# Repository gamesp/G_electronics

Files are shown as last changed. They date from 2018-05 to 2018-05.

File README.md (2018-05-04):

## Pi GAMESP Robot Electronics

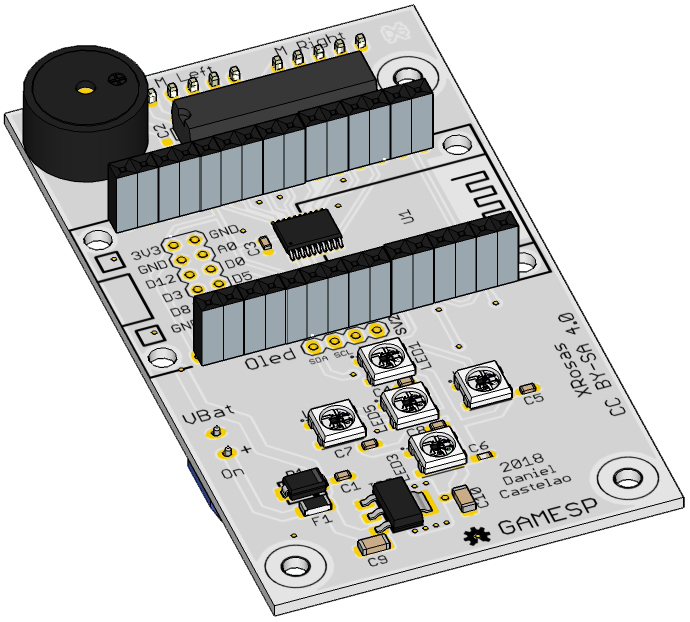
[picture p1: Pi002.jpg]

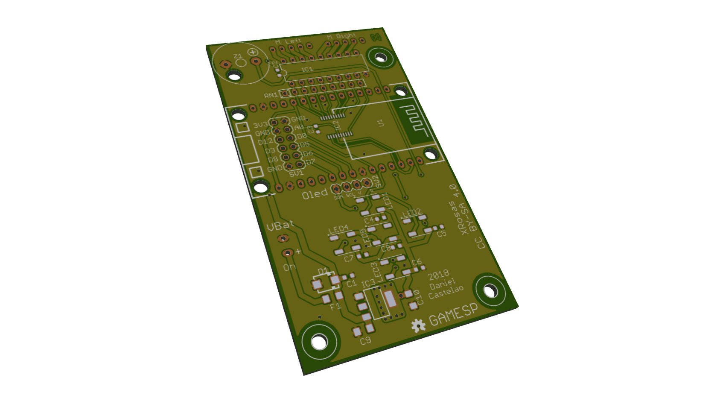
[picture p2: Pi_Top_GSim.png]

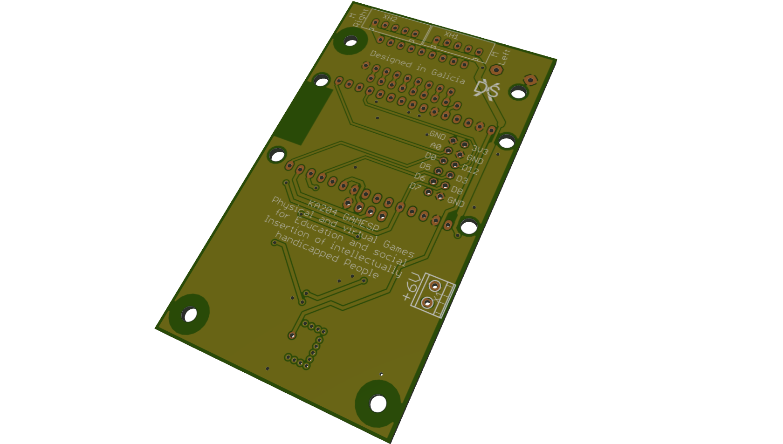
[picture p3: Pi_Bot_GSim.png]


## Catalog

- Esquematic and PCB (by [Xdesig][XDE01])

- Gerber 274 machines compatible.

- STL for slicer

- Images mounting Process and connections

- 3d sim (SketchUp, Private use)

## NodeMCU
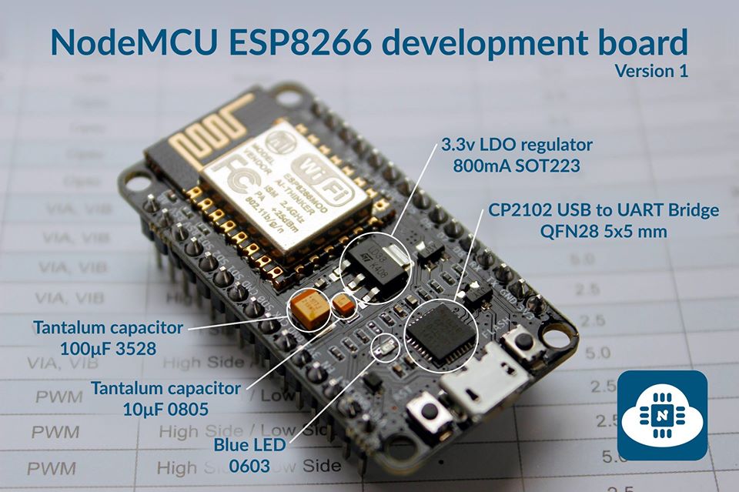
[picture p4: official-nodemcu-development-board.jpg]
devkit-v1.0
  

- devkit-v1.0 [NodeMCU]

- NodeMCU License [NodeMCU_LIC]

## License

Every content in this repo, otherwise specified under subdirectories, is
licensed under [Creative Commons BY-SA](LICENSE).

[XDE01]: https://twitter.com/xdesig

[NodeMCU_LIC]: https://github.com/nodemcu/nodemcu-devkit-v1.0/blob/master/LICENSE
[NodeMCU]: https://github.com/nodemcu/nodemcu-devkit-v1.0

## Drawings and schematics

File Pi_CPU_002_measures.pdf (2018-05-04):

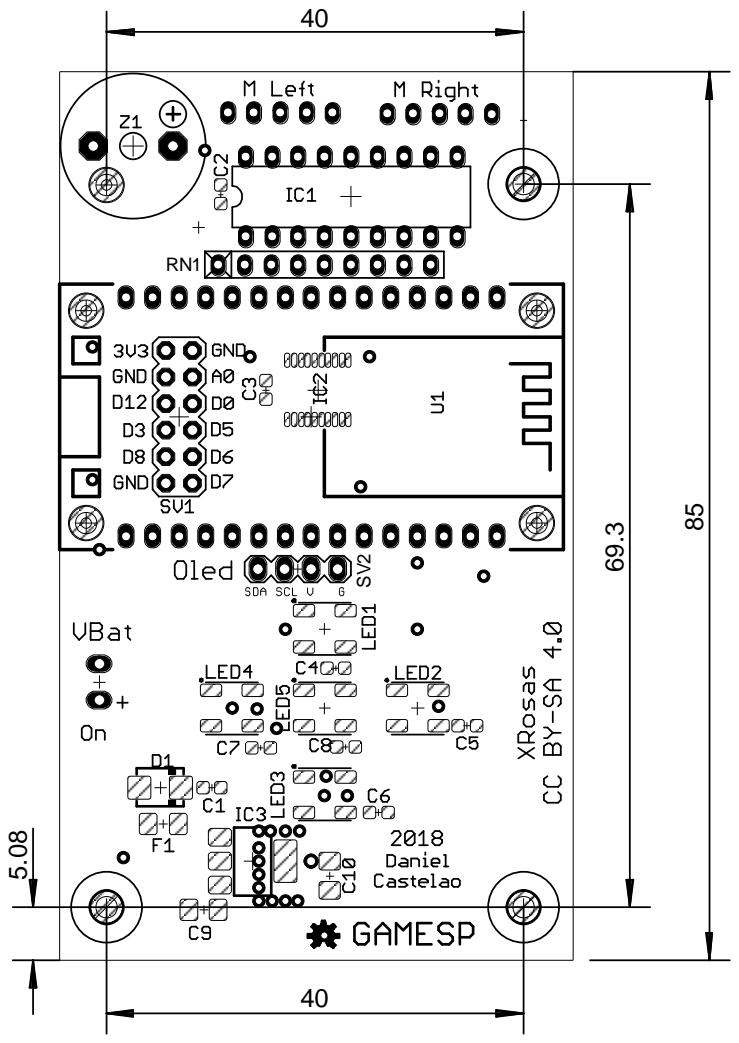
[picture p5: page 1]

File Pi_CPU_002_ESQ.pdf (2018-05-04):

## NodeMCU DEVKIT V1.0

## Steepers

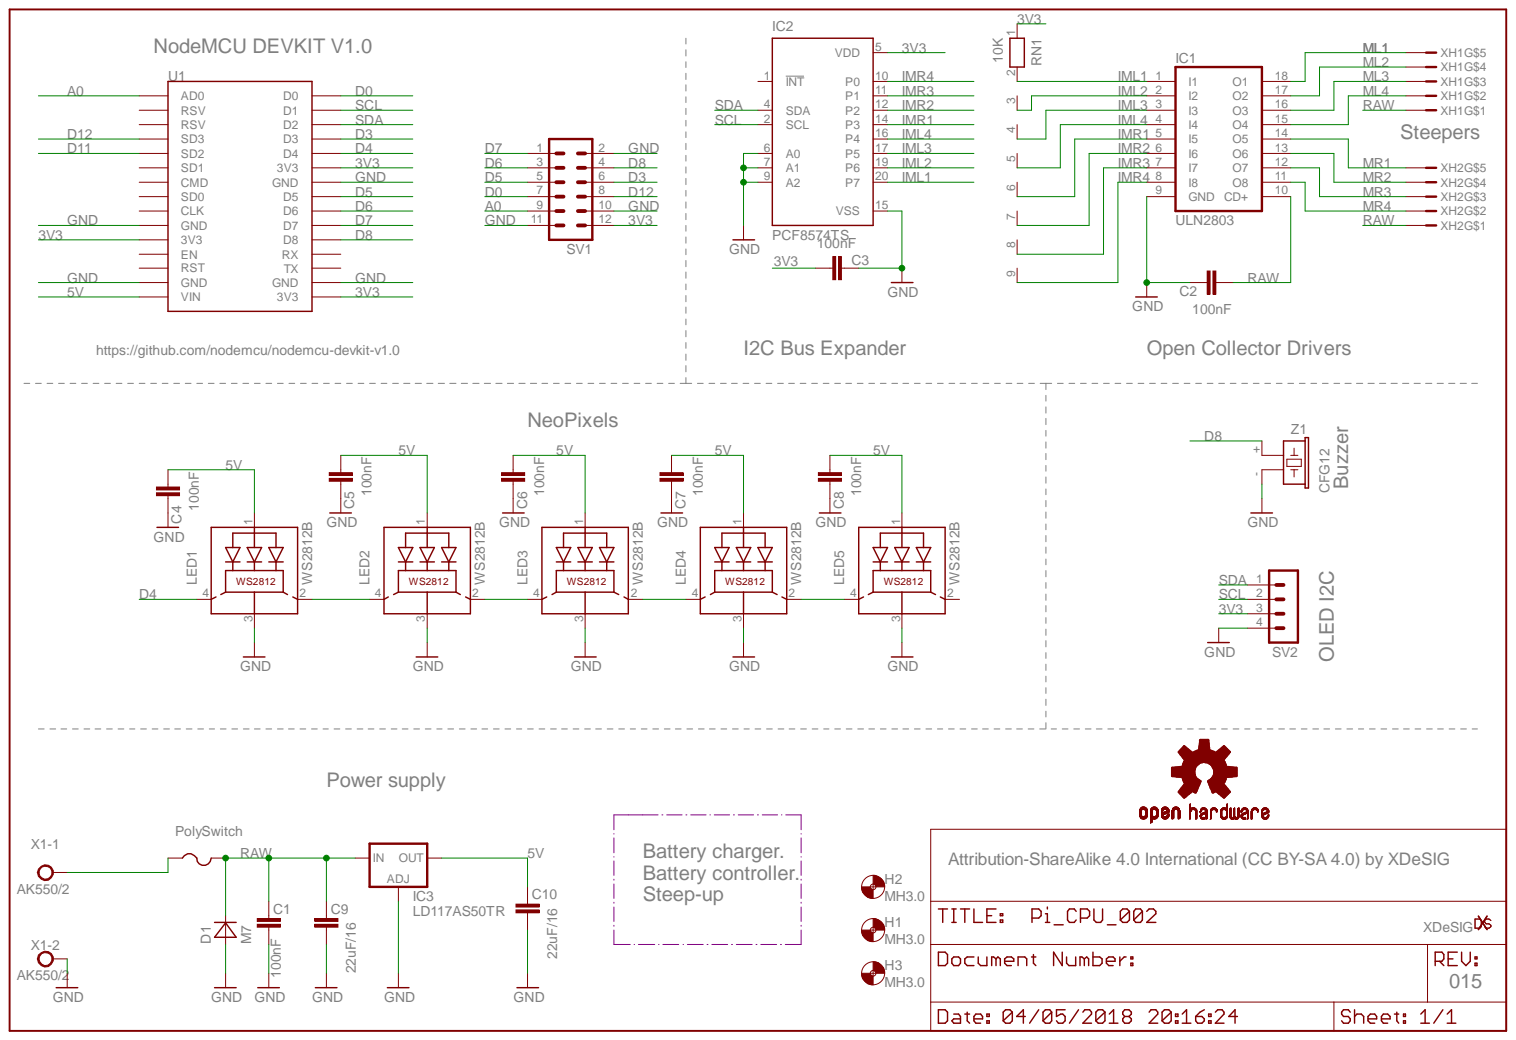
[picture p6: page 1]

https://github.com/nodemcu/nodemcu-devkit-v1.0

Attribution-ShareAlike 4.0 International (CC BY-SA 4.0) by XDeSIG

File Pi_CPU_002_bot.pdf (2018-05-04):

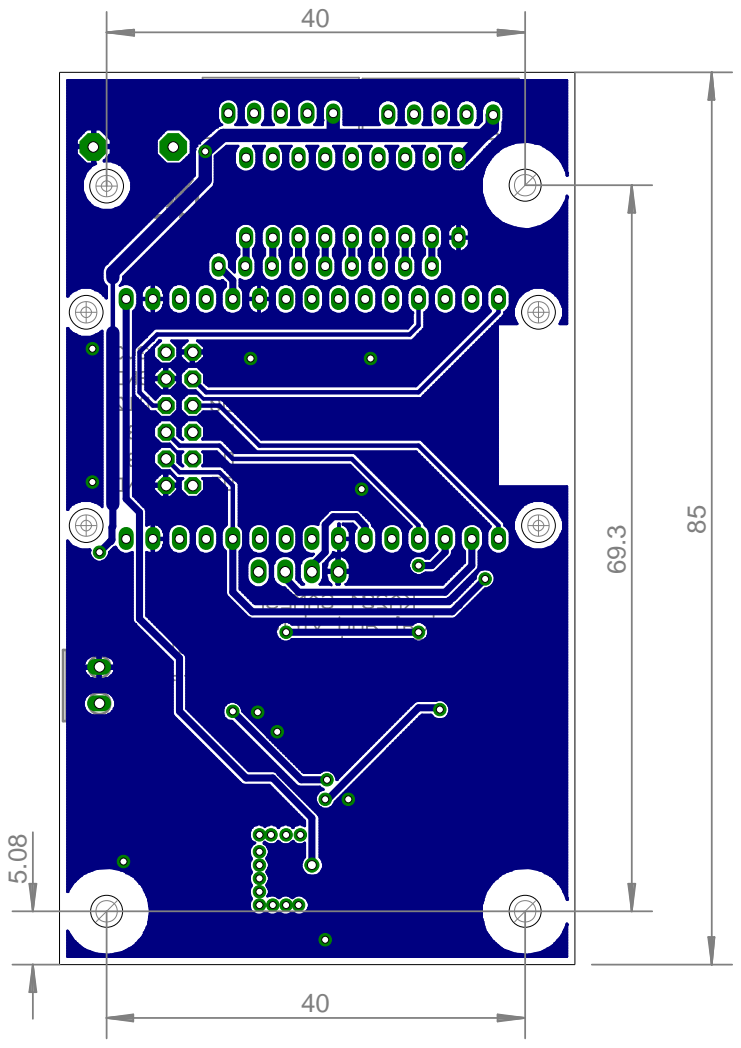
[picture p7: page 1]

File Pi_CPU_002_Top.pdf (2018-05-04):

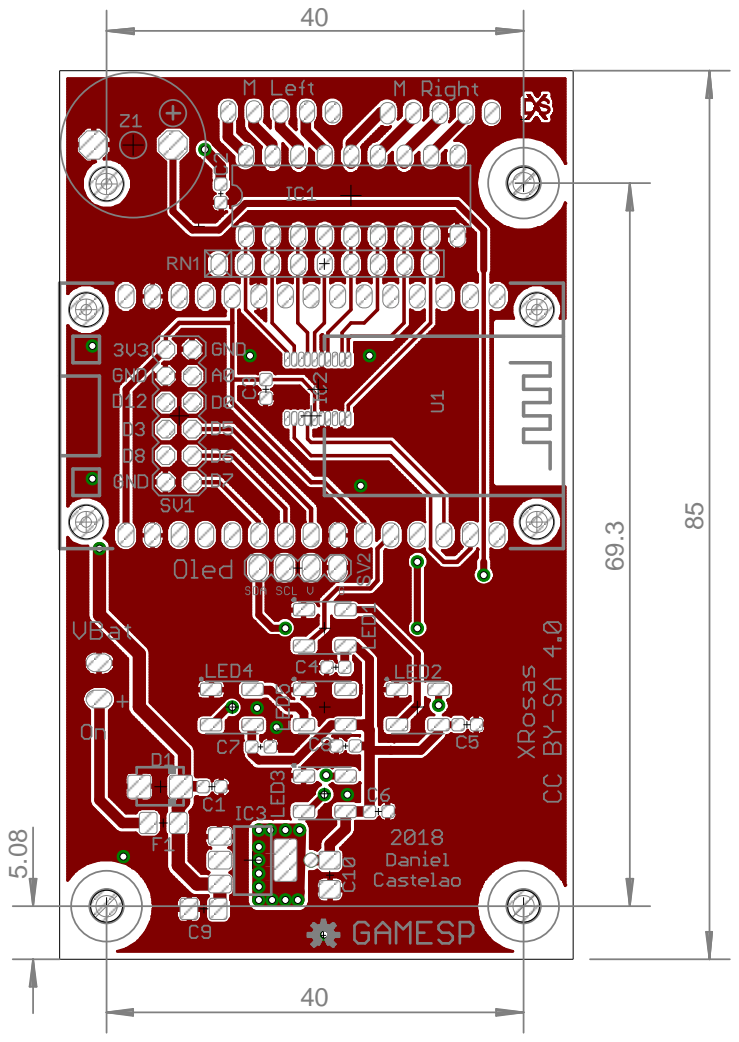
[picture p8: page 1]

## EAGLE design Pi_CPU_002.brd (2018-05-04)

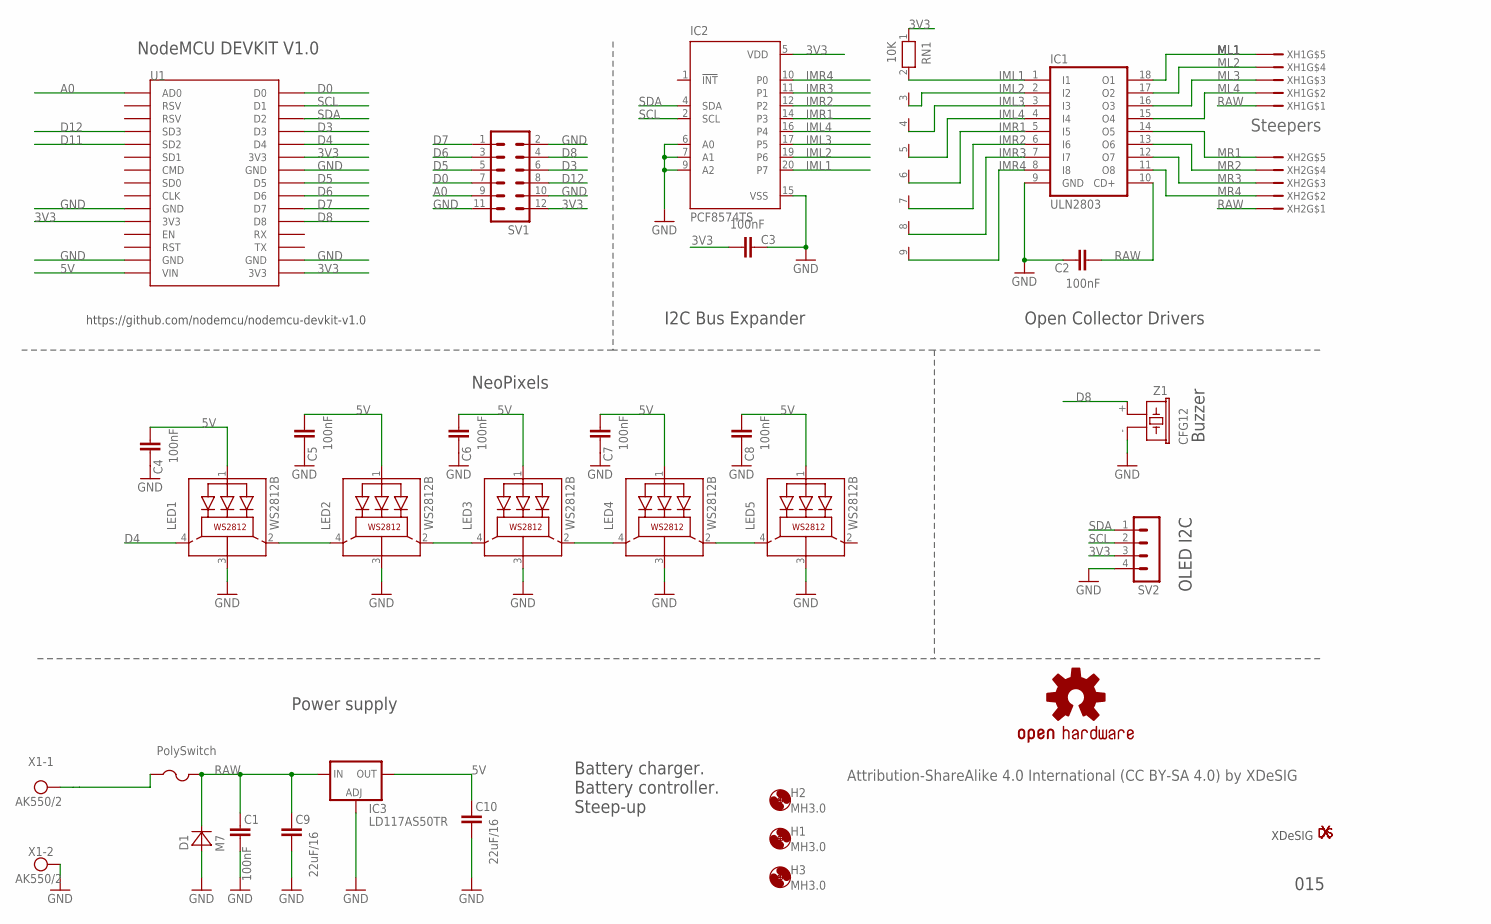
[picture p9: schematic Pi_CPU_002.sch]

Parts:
C1, C2, C3, C4, C5, C6, C7, C8: 100nF; C0603K
C9, C10: 22uF/16; C1206
D1: M7; SMA
F1: PolySwitch; R1206
H1, H2, H3: MH3.0; 3,0
IC1: ULN2803; DIL18
IC2: PCF8574TS; SSOP20
IC3: LD117AS50TR; SOT223
LED1, LED2, LED3, LED4, LED5: WS2812B; 5050-4
LOGO2: OSHW-LOGOS; OSHW-LOGO-S
RN1: 10K; RN-9
SV1: MA06-2
SV2: MA04-1
U1: ESP12E_DEVKIT
U$13: XDESIG_XDESIG21; XDESIG_XDESIG
X1: AK550/2
XDS1: XDESIG; XDESIG_CU_2
XH1, XH2: B5B-XH-A
Z1: CFG12; F/CM12P

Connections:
3V3: C3.2, IC2.5 (VDD), RN1.1, SV1.12, SV2.3, U1.3V3@0 (3V3), U1.3V3@1 (3V3), U1.3V3@2 (3V3)
5V: C4.2, C5.2, C6.2, C7.2, C8.2, C10.2, IC3.4 (OUT), LED1.1 (LEDVDD), LED2.1 (LEDVDD), LED3.1 (LEDVDD), LED4.1 (LEDVDD), LED5.1 (LEDVDD), U1.VIN
A0: SV1.9, U1.AD0
D0: SV1.7, U1.D0
D3: SV1.6, U1.D3
D4: LED1.4 (DI), U1.D4
D5: SV1.5, U1.D5
D6: SV1.3, U1.D6
D7: SV1.1, U1.D7
D8: SV1.4, U1.D8, Z1.+ (1)
D11: U1.SD2
D12: SV1.8, U1.SD3
GND: C1.1, C2.1, C3.1, C4.1, C5.1, C6.1, C7.1, C8.1, C9.1, C10.1, D1.A, IC1.9 (GND), IC2.6 (A0), IC2.7 (A1), IC2.9 (A2), IC2.15 (VSS), IC3.1 (ADJ), LED1.3 (GND), LED2.3 (GND), LED3.3 (GND), LED4.3 (GND), LED5.3 (GND), SV1.2, SV1.10, SV1.11, SV2.4, U1.GND@0 (GND), U1.GND@1 (GND), U1.GND@2 (GND), U1.GND@3 (GND), X1.2, Z1.- (2)
IML1: IC1.1 (I1), IC2.20 (P7), RN1.2
IML2: IC1.2 (I2), IC2.19 (P6), RN1.3
IML3: IC1.3 (I3), IC2.17 (P5), RN1.4
IML4: IC1.4 (I4), IC2.16 (P4), RN1.5
IMR1: IC1.5 (I5), IC2.14 (P3), RN1.6
IMR2: IC1.6 (I6), IC2.12 (P2), RN1.7
IMR3: IC1.7 (I7), IC2.11 (P1), RN1.8
IMR4: IC1.8 (I8), IC2.10 (P0), RN1.9
ML1: IC1.18 (O1), XH1.P$5
ML2: IC1.17 (O2), XH1.P$4
ML3: IC1.16 (O3), XH1.P$3
ML4: IC1.15 (O4), XH1.P$2
MR1: IC1.14 (O5), XH2.P$5
MR2: IC1.13 (O6), XH2.P$4
MR3: IC1.12 (O7), XH2.P$3
MR4: IC1.11 (O8), XH2.P$2
unnamed: F1.1, X1.1
unnamed: LED1.2 (DO), LED2.4 (DI)
unnamed: LED3.2 (DO), LED4.4 (DI)
unnamed: LED2.2 (DO), LED3.4 (DI)
unnamed: LED4.2 (DO), LED5.4 (DI)
RAW: C1.2, C2.2, C9.2, D1.C, F1.2, IC1.10 (CD+), IC3.3 (IN), XH1.P$1, XH2.P$1
SCL: IC2.2 (SCL), SV2.2, U1.D1
SDA: IC2.4 (SDA), SV2.1, U1.D2

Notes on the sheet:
Steepers
Attribution-ShareAlike 4.0 International (CC BY-SA 4.0) by XDeSIG
XDeSIG
015
OLED I2C
NeoPixels
NodeMCU DEVKIT V1.0
I2C Bus Expander
Open Collector Drivers
Buzzer
Power supply
Battery charger. Battery controller. Steep-up
https://github.com/nodemcu/nodemcu-devkit-v1.0

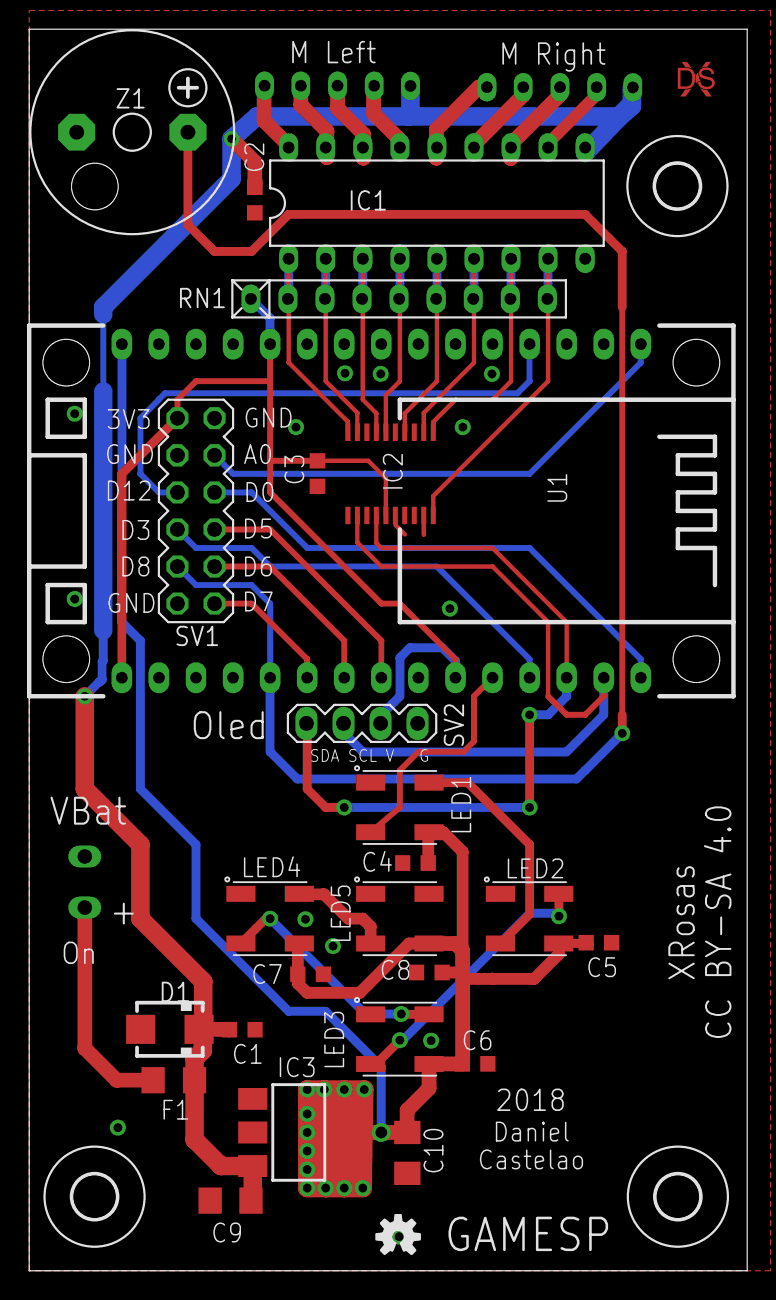
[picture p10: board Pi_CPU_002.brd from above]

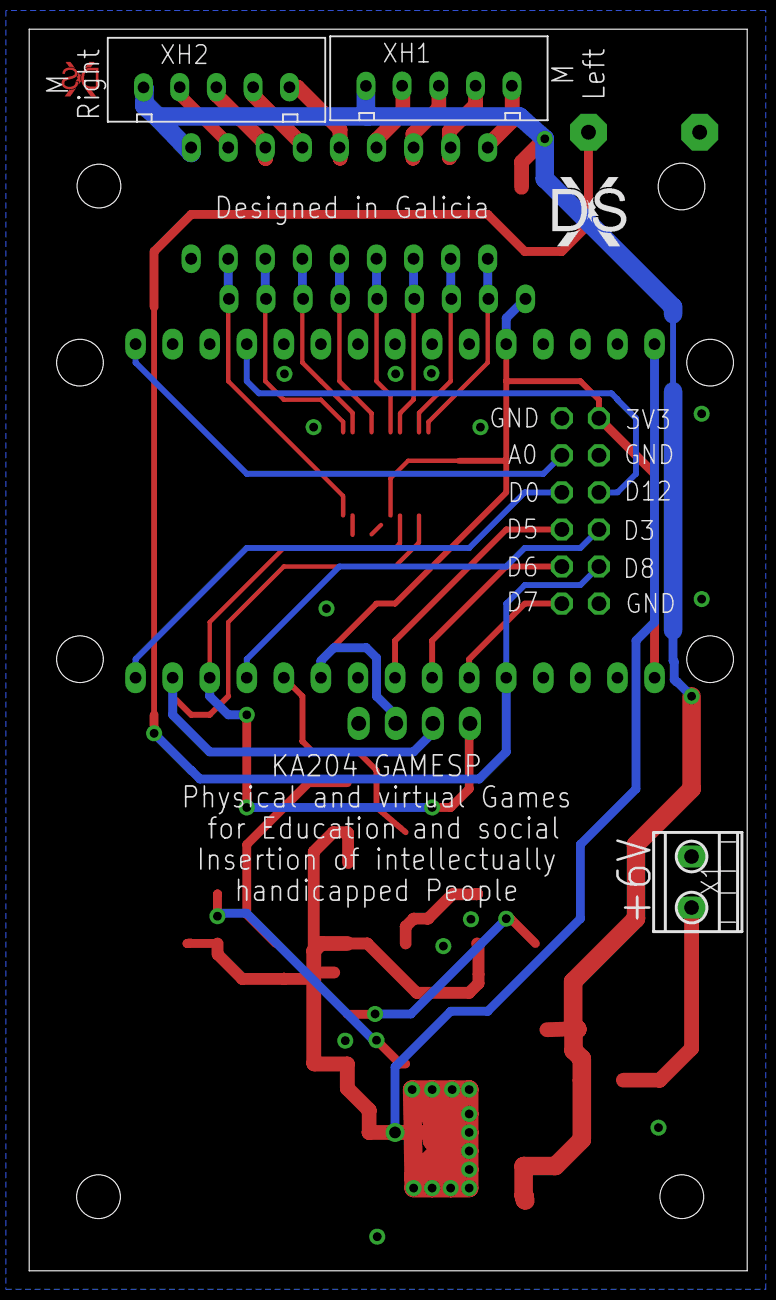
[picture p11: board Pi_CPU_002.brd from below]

Board: 2 copper layers, 49.2 x 85.1 mm, 34 parts (4 on the bottom side), 36 nets.

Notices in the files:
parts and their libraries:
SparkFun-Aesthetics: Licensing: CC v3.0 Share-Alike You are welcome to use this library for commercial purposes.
